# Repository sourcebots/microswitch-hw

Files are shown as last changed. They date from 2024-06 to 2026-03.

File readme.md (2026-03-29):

# Microswitch PCB

As part of the Smallpeice summer school, students create sensors to mount on their robots. Previously, this has been done using breadboards and veroboard. This suffered from issues with fitting the microswitch pins into the breadboards and mounting the board to the robot.

As such, this PCB is designed to be a simple breakout board for a microswitch. It has footprints for a microswitch, debouncing circuitry and a 3-pin screw terminal to connect to the board. The board is designed to be mounted on 2020 aluminium extrusion chassis with M5 screws.

3D PCB

PCB front
PCB back

Schematic

## Components
- [Right-angle microswitch](https://www.lcsc.com/product-detail/C504864.html): C504864
- [Screw terminal block](https://www.lcsc.com/product-detail/C5188435.html): C5188435

## Resources

- [Schematic PDF](https://sourcebots.github.io/microswitch-hw/Schematic/switch_pcb-schematic.pdf)
- [Interactive BOM](https://sourcebots.github.io/microswitch-hw/Assembly/switch_pcb-ibom.html)
- [BOM CSV](https://sourcebots.github.io/microswitch-hw/BoM/Generic/switch_pcb-bom.csv)
- [Gerbers (JLCPCB format)](https://sourcebots.github.io/microswitch-hw/Manufacturers/switch_pcb-_JLCPCB_compress.zip)
- [3D model (STEP)](https://sourcebots.github.io/microswitch-hw/3D/switch_pcb-3D.step)
- [Assembly drawings](https://sourcebots.github.io/microswitch-hw/PCB/PDF/switch_pcb-assembly.pdf)

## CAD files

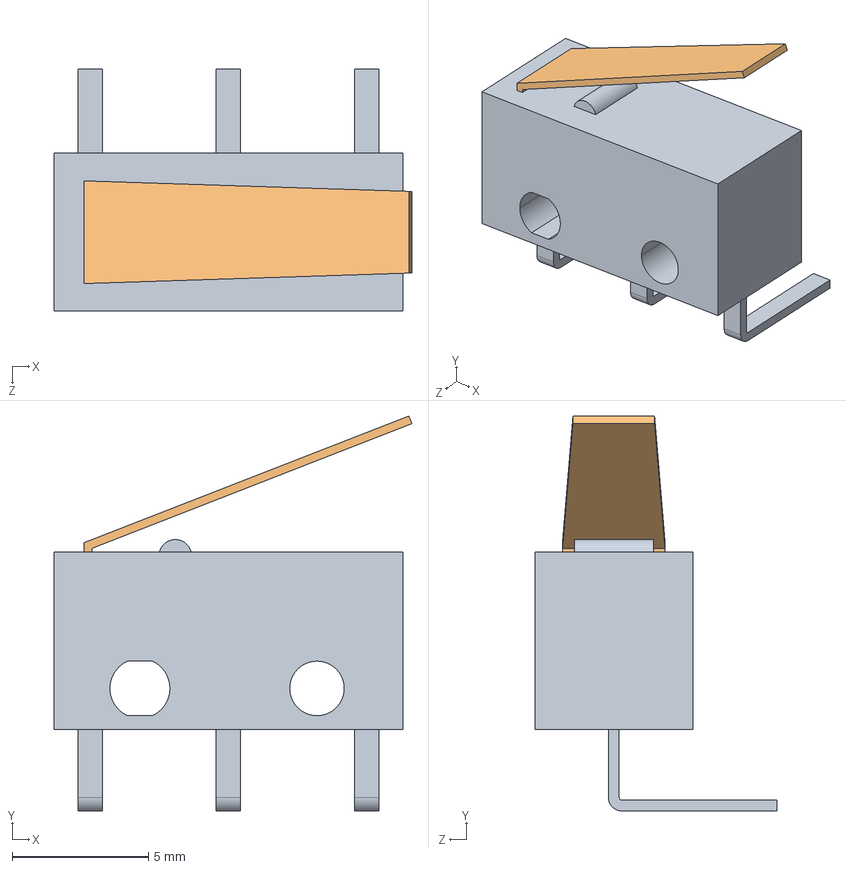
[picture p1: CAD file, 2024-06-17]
D2F-01L-A-3DModel.STEP
13.1 x 14.5 x 8.90 mm
D2F_01L_A.BASE
D2F_01L_A.ACTUATOR

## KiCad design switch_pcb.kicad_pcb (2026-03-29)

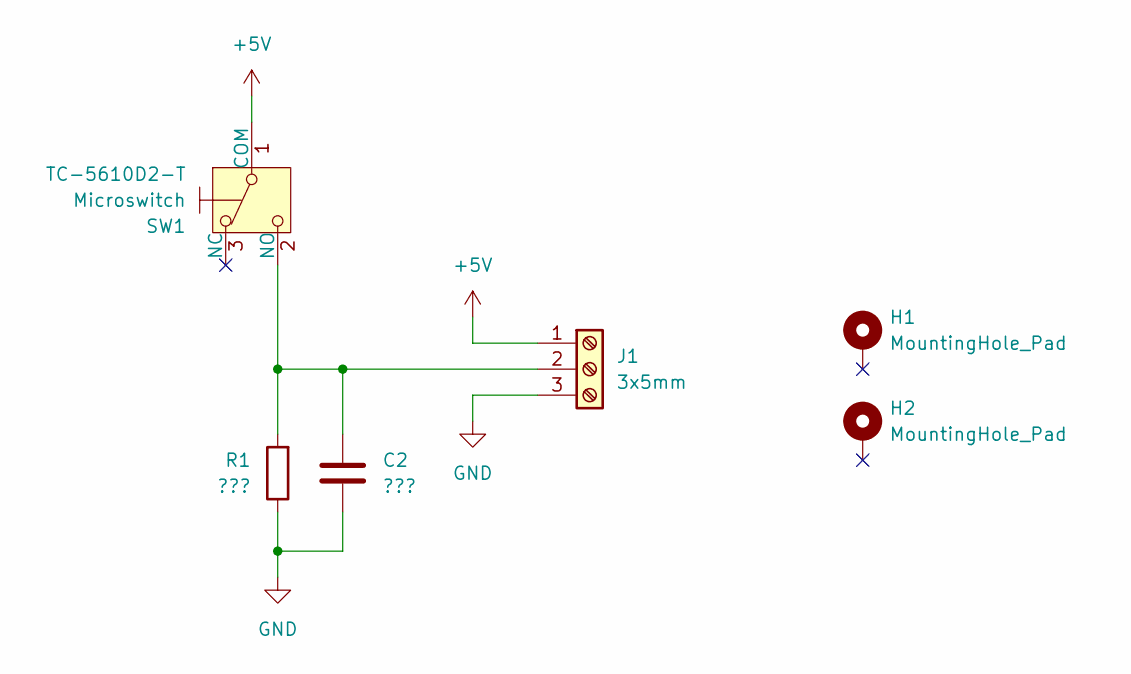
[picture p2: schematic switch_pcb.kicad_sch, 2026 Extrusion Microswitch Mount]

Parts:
C2: ???; C_Disc_D9.0mm_W5.0mm_P5.00mm
H1, H2: MountingHole_Pad; MountingHole_5.3mm_M5_ISO7380_Pad
J1: 3x5mm; TerminalBlock_Phoenix_MKDS-1,5-3_1x03_P5.00mm_Horizontal; JLC C5188435
R1: ???; R_Axial_DIN0207_L6.3mm_D2.5mm_P10.16mm_Horizontal
SW1: Microswitch; TC-5610D2-T; JLC C504864

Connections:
+5V: J1.1, SW1.1 (COM)
GND: C2.2, J1.3, R1.1
unnamed: C2.1, J1.2, R1.2, SW1.2 (NO)

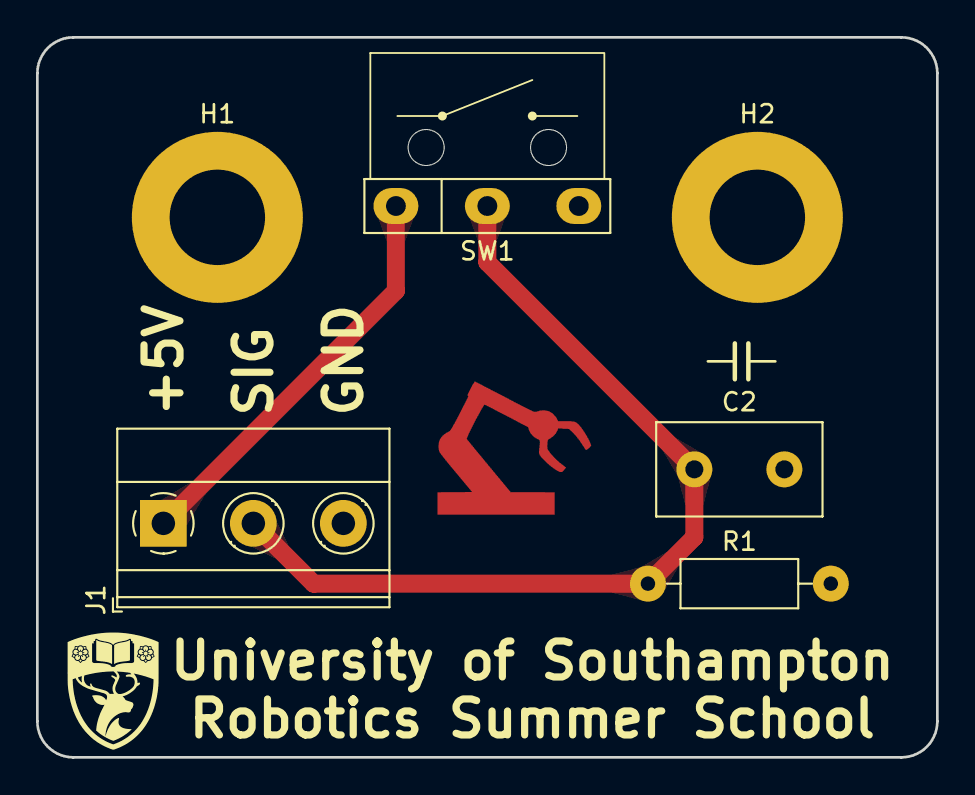
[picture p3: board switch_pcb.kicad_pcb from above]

Board: 2 copper layers, 50.0 x 40.0 mm, 6 parts (0 on the bottom side), 3 nets.

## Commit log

2024-05-13 Base schematic
    [switch_pcb.kicad_pcb, switch_pcb.kicad_sch]
2024-05-13 Add some footprints and mounting holes
    [switch_pcb.kicad_sch]
2024-05-14 Switch to only breaking out the normally open circuit
    [switch_pcb.kicad_sch]
2024-06-17 Create footprints
    [switch_pcb.kicad_sch]
2024-06-17 Setup PCB DRC
    [switch_pcb.kicad_pcb]
2024-06-17 Rough first layout
    [switch_pcb.kicad_pcb]
2024-06-17 Add rough 3D model for switch
    [D2F-01L-A-3DModel.STEP, switch_pcb.kicad_pcb]
2024-06-18 Reworked layout
    [switch_pcb.kicad_pcb]
2024-06-18 Improve silkscreen, add SRO logo
    [switch_pcb.kicad_pcb]
2024-06-19 Switch to ENIG
    [switch_pcb.kicad_pcb]
2024-06-23 Make SRO arm fill copper Not just soldermask
2024-06-23 Extend PCB, add course name and logo, add initial area on PCB
    [switch_pcb.kicad_pcb]
2024-06-23 Review feedback Center PCB on page Remove 5V plane & use teardrops Change circuit to be pulled up & switched low
    [switch_pcb.kicad_pcb, switch_pcb.kicad_sch]
2024-06-24 Improve DRC
    [switch_pcb.kicad_pcb]
2024-06-24 Switch back to the previous circuit with switch at the top
    [switch_pcb.kicad_pcb, switch_pcb.kicad_sch]
2026-03-22 Update to "UoS Robotics Summer School" Switch to UoS logo Update to Kicad v9
    [switch_pcb.kicad_pcb, switch_pcb.kicad_sch]
2026-03-22 Upgrade CI to Kicad 9
2026-03-29 Setup for serial number
    [switch_pcb.kicad_pcb]
